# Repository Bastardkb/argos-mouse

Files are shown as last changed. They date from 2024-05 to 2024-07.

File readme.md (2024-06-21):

# Argos mouse

An ergonomic mouse with a trackpad.

Engineered to be a full mouse replacement solution with high-quality, custom-developed components.

# Disclaimer

**This is a work in progress and not meant for ordering yet.**

# Required components

## 3d prints

The STL files are included in this Github repository, in the `files` folder.

| Description | File | Notes |
| --- | --- | --- |
| Case | `main.3mf` | |
| Switch holder | `switches.3mf` | |
| Trackpad holder | `trackpad holder.3mf` |  |
| Tent | `tent.3mf` | Optional |
| Trackpad holder | `trackpad holder.3mf` |  |

## Hardware

You can get a kit from Bastard keyboards directly. Alternatively, you can source components yourself.

| Part name | Amount | Notes |
| --- | --- | --- |
| Heated screw insert, M3x5x5 | 2 |  |
| M3 8mm torx screw | 3 | |
| M3 square nut | 1 | |
| Cirque trackpad | 1 | 40mm curved || 12-position FPC cable, 0.5mm pitch, same side contacts | 1 | Farnell, length TBD |

Optional parts if you're using the tents

| Part name | Amount | Notes |
| --- | --- | --- |
| Heated screw insert, M3x5x5 | 3 |  |
| M3 8mm torx screw | 3 | |

## PCBs

You will need 2 PCBs for this mouse.

### Controller

- A RP2040-based board, the brain of the mouse
- The release section includes gerbers, BOM and POS files
- Order in 1.2mm thickness

### Switches

- Connects all the switches and add per-key RGB capabilities
- https://github.com/Bastardkb/argos-switches-pcb
- Order in 0.6mm thickness
- You can also instead handsolder or use amoebas, but then might have to modify the firmware.

## Print instructions

- Material: PLA
- Layer height: .15mm or .2mm
- Supports: everywhere*

*If using prusaslicer, using auto-painted supports will work as well.

# Build guide

You can find detailed instruction on the online documentation linked below.

# Links

- Discord: https://bastardkb.com/discord
- Website: https://bastardkb.com/
- Docs: https://docs.bastardkb.com

# License 

This work is licensed under a Creative Commons Attribution-NonCommercial-ShareAlike 4.0 International License.

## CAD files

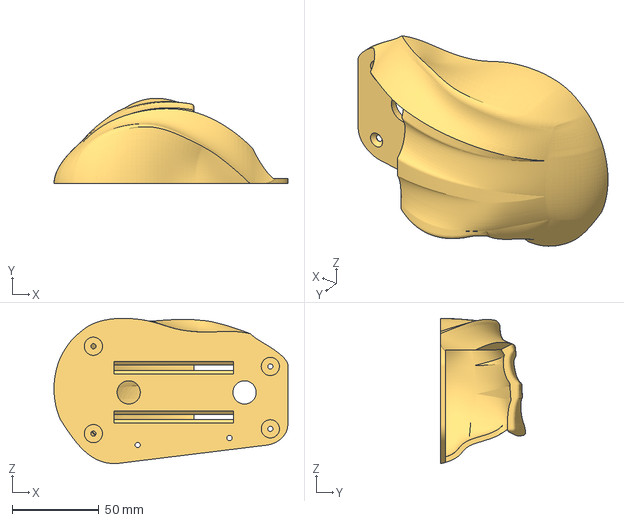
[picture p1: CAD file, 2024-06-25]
main.3mf
134.6 x 49.1 x 83.6 mm

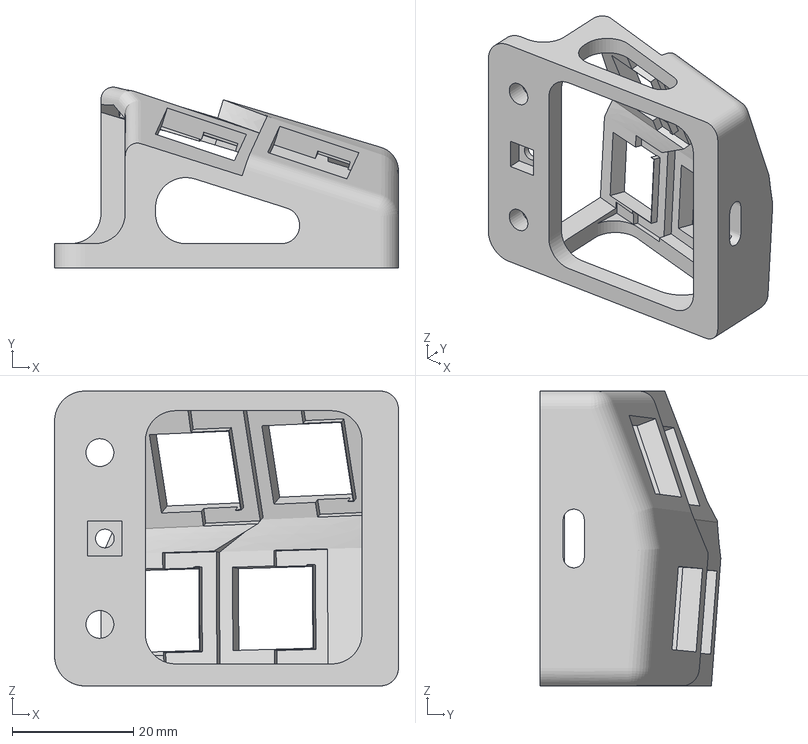
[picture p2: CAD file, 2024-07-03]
switches.3mf
56.8 x 29.8 x 48.7 mm

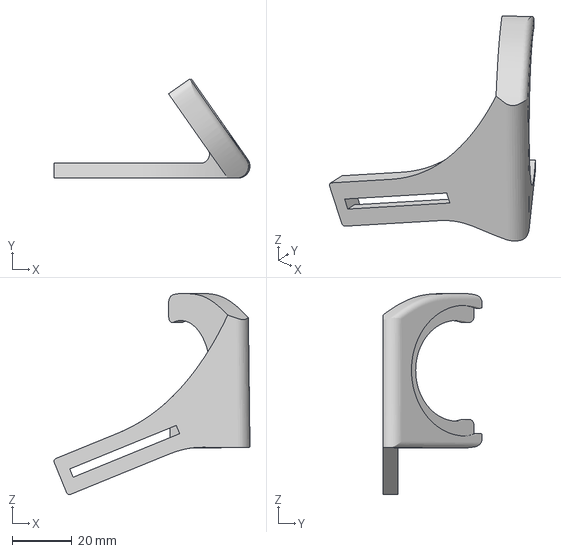
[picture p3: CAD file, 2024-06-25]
trackpad holder.3mf
65.7 x 33.3 x 67.5 mm

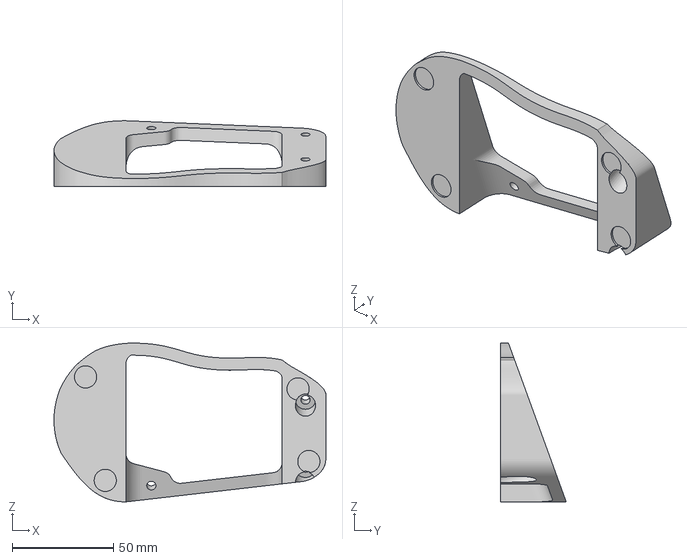
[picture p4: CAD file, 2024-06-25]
tent.3mf
134.6 x 32.5 x 78.6 mm

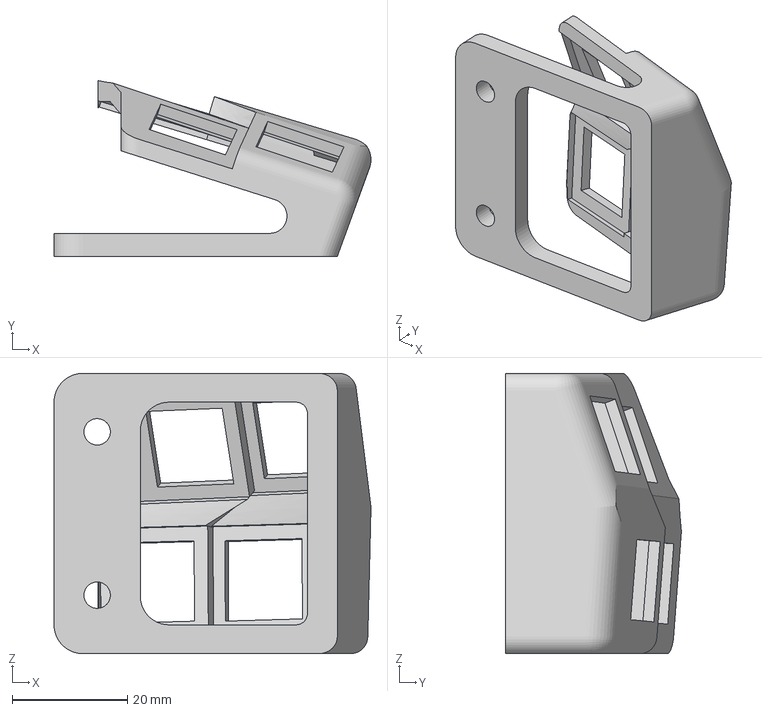
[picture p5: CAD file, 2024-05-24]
switches_2mm.3mf
55.1 x 30.6 x 48.7 mm

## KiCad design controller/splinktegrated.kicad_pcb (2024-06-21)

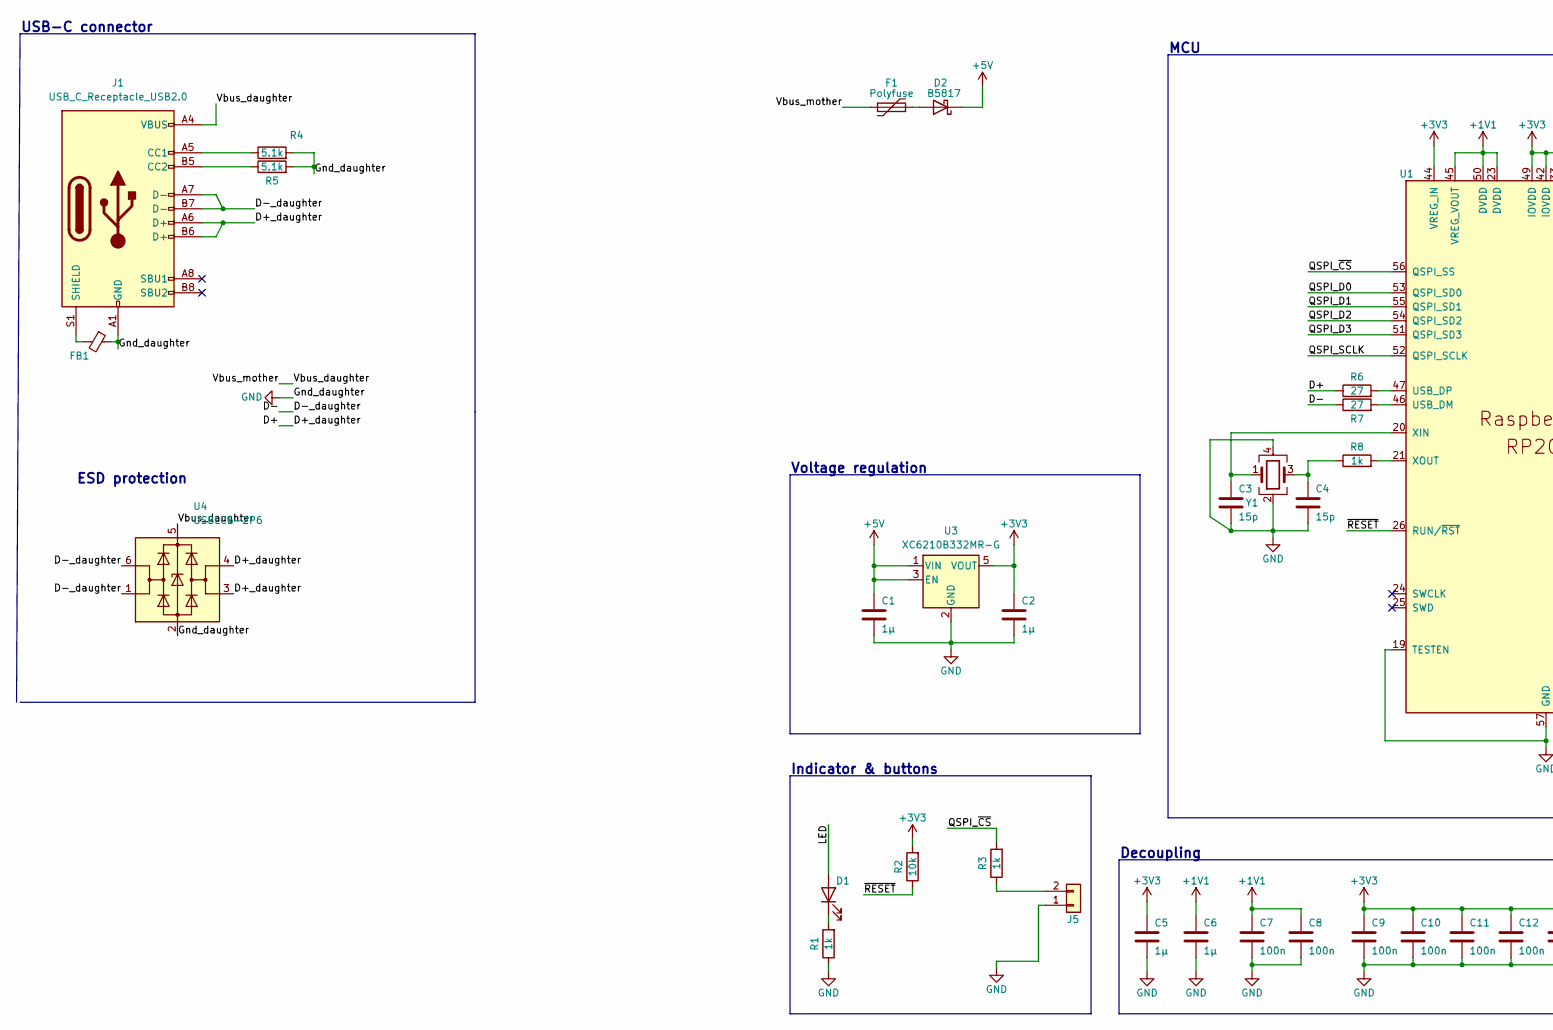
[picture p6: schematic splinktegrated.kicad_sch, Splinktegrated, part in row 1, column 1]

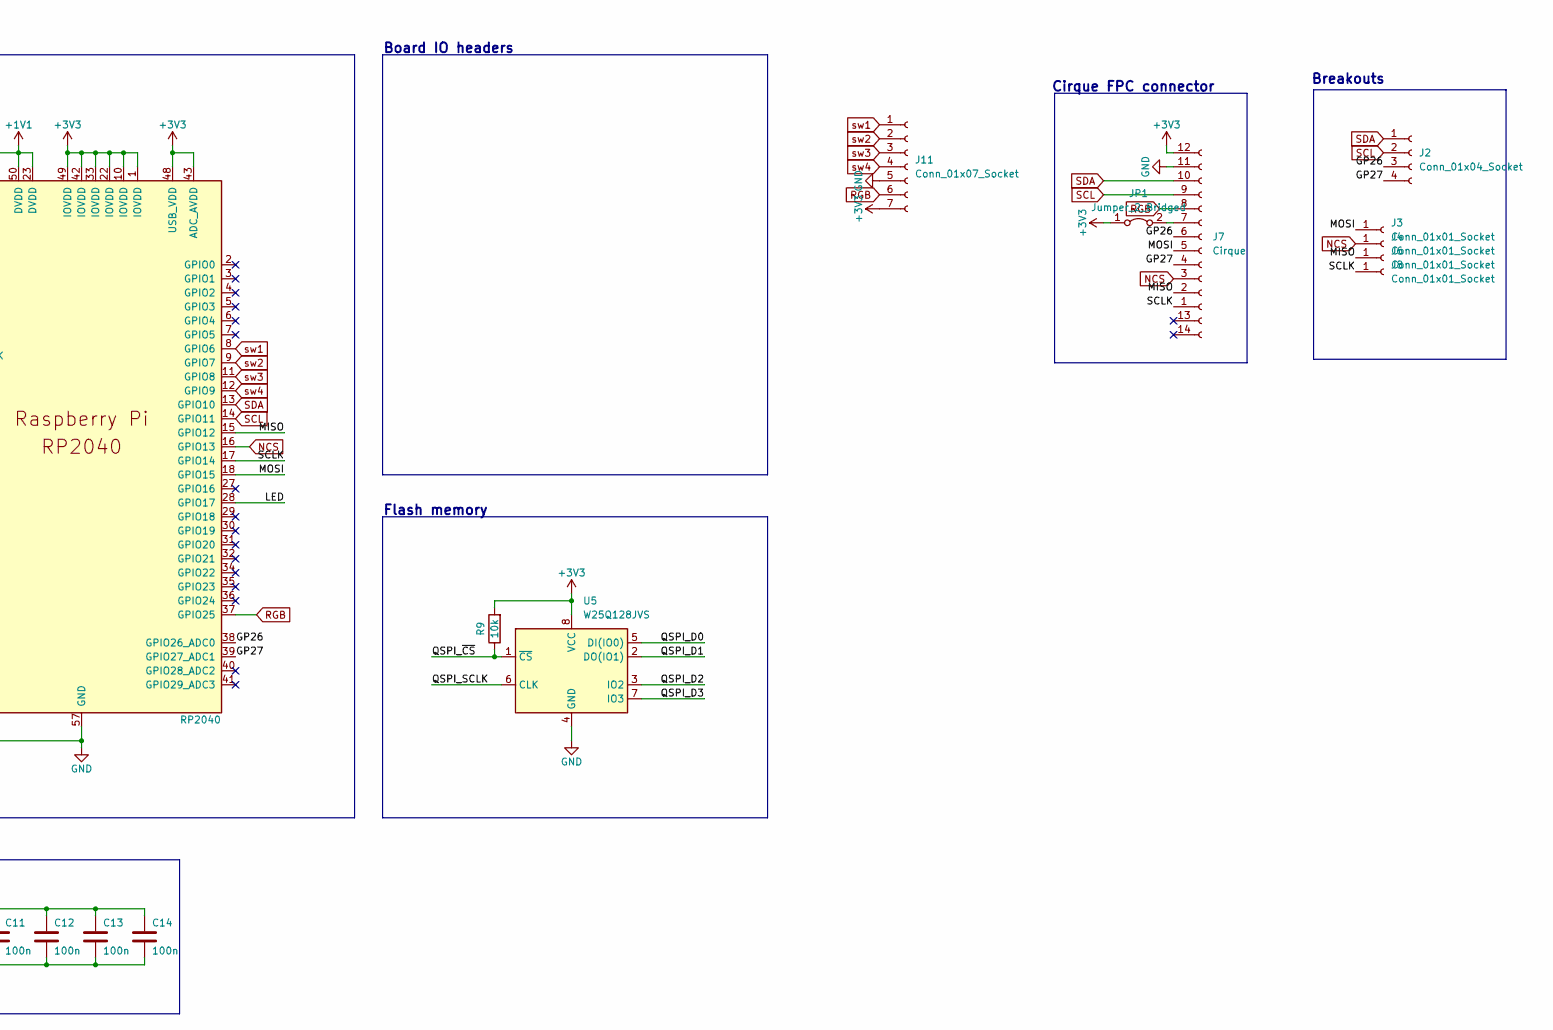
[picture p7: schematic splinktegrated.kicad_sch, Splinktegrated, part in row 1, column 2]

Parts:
C1, C2: 1µ; C_0603_1608Metric; LCSC C19666
C3, C4: 15p; C_0402_1005Metric; LCSC C1548
C5, C6: 1µ; C_0402_1005Metric; LCSC C52923
C7, C8, C9, C10, C11, C12, C13, C14: 100n; C_0402_1005Metric; LCSC C1525
D1: LED; LED_0402_1005Metric; LCSC C130719
D2: B5817; D_SOD-323; LCSC C123899
F1: Polyfuse; Fuse_0603_1608Metric; LCSC C69679
FB1: FerriteBead_Small; L_0603_1608Metric; LCSC C98288
J1: USB_C_Receptacle_USB2.0; GT-USB-7014C; LCSC C223907
J2: Conn_01x04_Socket; PinSocket_1x04_P2.54mm_Vertical
J3, J4, J6, J8: Conn_01x01_Socket; PinHeader_1x01_P1.27mm_SMD
J5: Conn_01x02; PinHeader_1x02_P1.27mm_Vertical
J7: Cirque; FPC-SMD_FPC05012-09200-.5mm
J11: Conn_01x07_Socket; PinSocket_1x07_P2.54mm_Vertical
JP1: Jumper_2_Bridged; SolderJumper-2_P1.3mm_Open_RoundedPad1.0x1.5mm
R1, R3, R8: 1k; R_0402_1005Metric; LCSC C11702
R2, R9: 10k; R_0402_1005Metric; LCSC C25744
R4, R5: 5.1k; R_0402_1005Metric; LCSC C25905
R6, R7: 27; R_0402_1005Metric; LCSC C25100
U1: RP2040; QFN-56-1EP_7x7mm_P0.4mm_EP3.2x3.2mm; LCSC C2040
U3: XC6210B332MR-G; SOT-23-5; LCSC C82942
U4: USBLC6-2P6; SOT-666
U5: W25Q128JVS; W25Q128JVPIQ
Y1: Crystal_GND24; Crystal_SMD_2520-4Pin_2.5x2.0mm; LCSC C2149204

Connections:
+1V1: C6.1, C7.1, C8.1, U1.23 (DVDD), U1.45 (VREG_VOUT), U1.50 (DVDD)
+3V3: C2.1, C5.1, C9.1, C10.1, C11.1, C12.1, C13.1, C14.1, J7.12, J11.7, JP1.1 (A), R2.2, R9.2, U1.1 (IOVDD), U1.10 (IOVDD), U1.22 (IOVDD), U1.33 (IOVDD), U1.42 (IOVDD), U1.43 (ADC_AVDD), U1.44 (VREG_IN), U1.48 (USB_VDD), U1.49 (IOVDD), U3.5 (VOUT), U5.8 (VCC)
+5V: C1.1, D2.1 (K), U3.1 (VIN), U3.3 (EN)
/D+: J1.A6 (D+), J1.B6 (D+), R6.1, U4.3 (I/O2), U4.4 (I/O2)
/D-: J1.A7 (D-), J1.B7 (D-), R7.1, U4.1 (I/O1), U4.6 (I/O1)
/GP26: J2.3, J7.6, U1.38 (GPIO26_ADC0)
/GP27: J2.4, J7.4, U1.39 (GPIO27_ADC1)
/LED: D1.2 (A), U1.28 (GPIO17)
/MISO: J6.1, J7.2, U1.15 (GPIO12)
/MOSI: J3.1, J7.5, U1.18 (GPIO15)
/QSPI_D0: U1.53 (QSPI_SD0), U5.5 (DI(IO0))
/QSPI_D1: U1.55 (QSPI_SD1), U5.2 (DO(IO1))
/QSPI_D2: U1.54 (QSPI_SD2), U5.3 (IO2)
/QSPI_D3: U1.51 (QSPI_SD3), U5.7 (IO3)
/QSPI_SCLK: U1.52 (QSPI_SCLK), U5.6 (CLK)
/QSPI_~CS: R3.2, R9.1, U1.56 (QSPI_SS), U5.1 (~CS)
/SCLK: J7.1, J8.1, U1.17 (GPIO14)
/Vbus_daughter: F1.1, J1.A4 (VBUS), J1.A9 (VBUS), J1.B4 (VBUS), J1.B9 (VBUS), U4.5 (VBUS)
/~RESET: R2.1, U1.26 (RUN/~RST)
GND: C1.2, C2.2, C3.2, C4.2, C5.2, C6.2, C7.2, C8.2, C9.2, C10.2, C11.2, C12.2, C13.2, C14.2, FB1.1, J1.A1 (GND), J1.A12 (GND), J1.B1 (GND), J1.B12 (GND), J5.1, J7.11, J11.5, R1.1, R4.2, R5.2, U1.19 (TESTEN), U1.57 (GND), U3.2 (GND), U4.2 (GND), U5.4 (GND), Y1.2, Y1.4
NCS: J4.1, J7.3, U1.16 (GPIO13)
unnamed: C4.1, R8.1, Y1.3
unnamed: D1.1 (K), R1.2
unnamed: D2.2 (A), F1.2
unnamed: J1.A5 (CC1), R4.1
unnamed: J1.B5 (CC2), R5.1
unnamed: FB1.2, J1.S1 (SHIELD)
unnamed: J5.2, R3.1
unnamed: J7.7, JP1.2 (B)
unnamed: R7.2, U1.46 (USB_DM)
unnamed: R6.2, U1.47 (USB_DP)
unnamed: C3.1, U1.20 (XIN), Y1.1
unnamed: R8.2, U1.21 (XOUT)
RGB: J7.8, J11.6, U1.37 (GPIO25)
SCL: J2.2, J7.9, U1.14 (GPIO11)
SDA: J2.1, J7.10, U1.13 (GPIO10)
sw1: J11.1, U1.8 (GPIO6)
sw2: J11.2, U1.9 (GPIO7)
sw3: J11.3, U1.11 (GPIO8)
sw4: J11.4, U1.12 (GPIO9)

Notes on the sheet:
Decoupling
Board IO headers
USB-C connector
Cirque FPC connector
Indicator & buttons
ESD protection
Voltage regulation
Breakouts
MCU
Flash memory

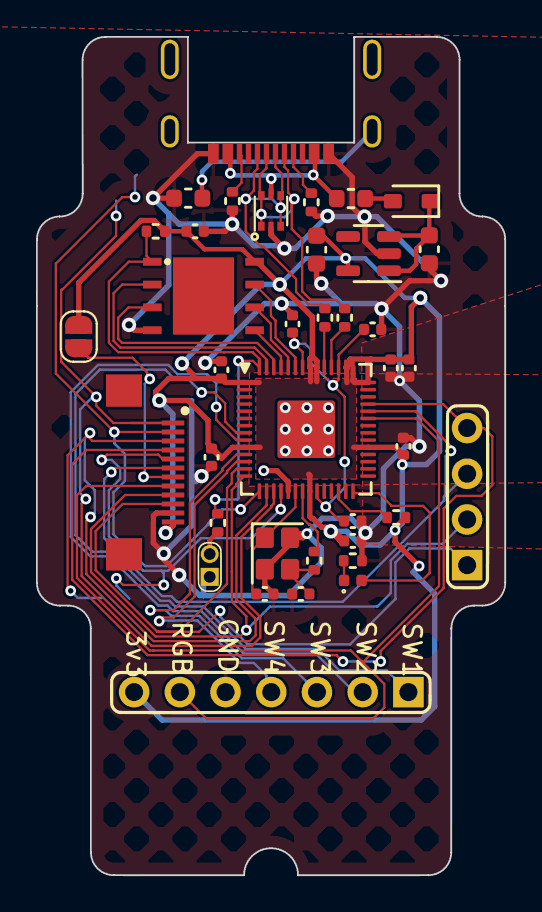
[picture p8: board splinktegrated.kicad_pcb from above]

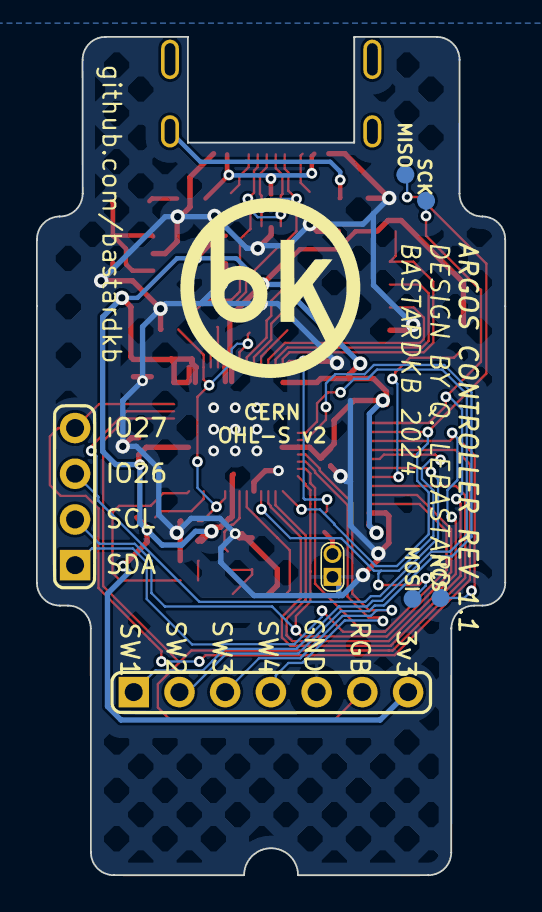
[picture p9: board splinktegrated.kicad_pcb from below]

Board: 2 copper layers, 26.0 x 46.6 mm, 42 parts (4 on the bottom side), 40 nets.

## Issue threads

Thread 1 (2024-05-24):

todo

bstiq, 2024-05-24:
- [x] SMD breakout pads in the back
- [x] pin holes in f360 model to check choc placement
- [x] spaghetti type connections on flex pcb
- [x] model usb hole in switch assembly
- [x] reverse flexplate connector on controller board
- [x] make controller board longer (5mm)
- [x] change SCK (GP22/SPI0) to eg. GP14/SPI1
- [ ] argos-controller: rename project files

bstiq, 2024-06-18:
closed, moved the last point to #3

Closed 2024-06-18.

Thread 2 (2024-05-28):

switches PCB improvements

bstiq, 2024-05-28:
- [ ] make flex pcb reversible to accomodate left handed mouse // WILL CAUSE ISSUE WITH CONNECTOR
- [ ] add switch number silkscreen next to the switches
- [ ] ~~slightly reduce angle~~
- [ ] bigger pin holes for switch plastic pins
- [ ] bigger solder pin holes

Closed 2024-06-20.

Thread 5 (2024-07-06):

3d models todo

bstiq, 2024-07-06:
- [ ] 2nd screw on trackpad holder
- [ ] guide for trackpad cable so it doesn't go out switch holder

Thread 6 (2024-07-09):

kit issues

bstiq, 2024-07-09:
- [ ] longer screws for trackpad holder connection to main body

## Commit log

2024-05-24 add controller
    [flex.kicad_pcb, flex.kicad_sch, splinktegrated.kicad_pcb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]
2024-05-25 remove vbus detect
    [splinktegrated.kicad_sch]
2024-05-25 flex PCB
    [flex.kicad_pcb, flex.kicad_sch]
2024-05-27 angle PCB
    [flex.kicad_pcb]
2024-05-27 3d work
    [main.3mf, switches.3mf, tent.3mf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]
2024-06-14 5mm longer controller
    [splinktegrated.kicad_pcb]
2024-06-18 revert connector
    [splinktegrated.kicad_pcb]
2024-06-18 change SCK pin
    [splinktegrated.kicad_pcb, splinktegrated.kicad_sch]
2024-06-18 update USB BOM
    [splinktegrated.kicad_pcb]
2024-06-18 add trackpad breakouts
    [splinktegrated.kicad_pcb, splinktegrated.kicad_sch]
2024-06-18 version number
    [splinktegrated.kicad_pcb]
2024-06-20 remove flex
    [flex.kicad_pcb, flex.kicad_sch]
2024-06-25 update 3d models
    [main.3mf, switches.3mf, tent.3mf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]
